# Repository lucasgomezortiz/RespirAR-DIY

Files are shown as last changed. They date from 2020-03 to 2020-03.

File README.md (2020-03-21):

# RespirAR DIY
###### Ante la urgencia y necesidad de los hospitales y centros de salud que combaten dia a dia con la Pandemia Covid-19(Coronavirus) buscamos la forma de generar un proyecto para aliviar la situacion actual, uno de los equipos mas necesiarios para combatir esta pandemia son los repiradores artifiales y de bajo presupuesto.
 
### EL PROYECTO ESTA EN FASE DESARROLLO
###### Toda ayuda es bienvenida para el desarrollo

Thingiverse: https://www.thingiverse.com/thing:4232749
fusion360: 

# Cualquier duda, sugerencia o aporte
Grupo de [facebook](https://www.facebook.com/groups/respiradormaker/) 
Instagram [@rejuntamaker](https://www.instagram.com/rejuntamaker/) [@lucasgomezortiz](https://www.instagram.com/lucasgomezortiz/)
### Este proyecto nace de [Reespirator](https://twitter.com/ReesistenciaT)

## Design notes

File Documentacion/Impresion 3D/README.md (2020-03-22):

# Adjunto los parametros utilizados en cada pieza

Para imprimir estas piezas no se requiere una gran impresora 3d, esta optimizado para cualquier tipo de impresoras fdm. 
*Ningun archivo requiere el uso de soportes, raft o balsa*

Aclaracion, las velocidades que utilice fueron a 75/mms por lo tanto el tiempo puede variar. pueden jugar con los datos que brindon, pero siempre pensado en la funcionalidad del dispositivo.
###### <u>MIS CONFIGURACION</u>
> **Flyingbear Ghost V4**
> Nozzle 0.5
> Tipo: Cerada
> Extrusor: Bowden
> S-Curve Acceleration
> Lineal Advance
> Version de Cura 4.4.1

> **Sura3D E1**
> Nozzle 0.4
> Tipo: abierta
> Extrusor: Bowden
> S-Curve Acceleration
> Lineal Advance
> Version de Cura 4.4.1

# ~~Acople OBSOLETO~~
> * Altura de capa: 0.2
> * Grosor de perimetro: 1mm
> * Cantidad de perimetros 3(Nozzle 0.5m) 4 * (Nozzle 0.4)
> * Infil: 25%
> * Patron: Lines
> * Ironing:Pattern ZigZag / Line Spacing 0.2
>> * Total: 00:07 Minutos

# AMBU
###### Piezas AMBU_A AMBU_B. Estas piezas lo ideal es imprimir con nozzle mas grandes (0.5 u 0.6)
> * Altura de capa: 0.35 (Nozzle 0.5)
> * Grosor de perimetro: 1mm
> * Cantidad de perimetros: 
> >* 3 (Nozzle 0.5m)
> >* 4 (Nozzle 0.4m)
> * Infil: 13%
> * Patron: Lines
> * Ironing:Pattern ZigZag / Line Spacing 0.2
>> * Total: 03:32hs C/U x2= 07:04hs

# Brazo/Puente
> * Altura de capa: 0.35 (Nozzle 0.5)
> * Grosor de perimetro: 1mm
> * Cantidad de perimetros: 
> >* 3 (Nozzle 0.5m)
> >* 4 (Nozzle 0.4m)
> * Infil: 10%
> * Patron: Lines
> * Ironing:Pattern ZigZag / Line Spacing 0.2
>> * Total: 01:20hs

###### Ender 3/PRO 
> * Rotar 45°
> * Ingresar cordenadas x 0.0119 Y 1.231

# Leva v0.3
> * Altura de capa: 0.35 (Nozzle 0.5)
> * Grosor de perimetro: 1mm
> * Cantidad de perimetros: 
> * Capas superiores e inferiores : 4 (1mm)
> >* 3 (Nozzle 0.5m)
> >* 4 (Nozzle 0.4m)
> * Infil: 13%
> * Patron: Lines
> * Ironing:Pattern ZigZag / Line Spacing 0.2
>> * Total: ~~02:07hs~~ 01:40hs

# Escuadras
> * Altura de capa: 0.35 (Nozzle 0.5)
> * Grosor de perimetro: 1mm
> * Cantidad de perimetros: 
> * Capas superiores e inferiores : 4 (1mm)
> >* 3 (Nozzle 0.5m)
> >* 4 (Nozzle 0.4m)
> * Infil: Se remplaza por perimetros
> * Patron: Lines
> * Ironing:Pattern ZigZag / Line Spacing 0.2
>> * Total: 00:57hs

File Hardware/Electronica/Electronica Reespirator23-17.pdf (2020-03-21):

### Sistema electrónico Reespirator

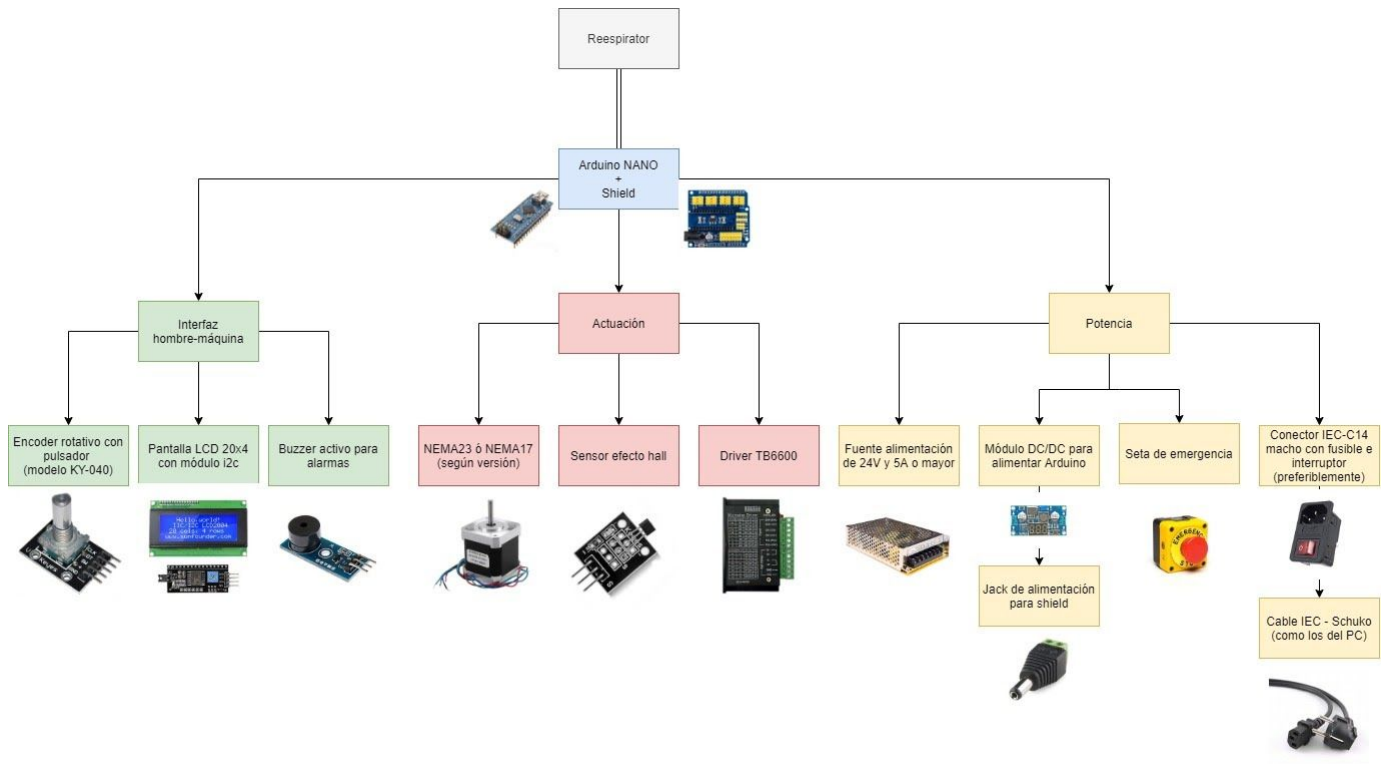
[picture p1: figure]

Se pretende hacer un sistema lo más sencillo posible, solo con los componentes que sean estrictamente necesarios y que estén disponibles en forma de módulo, para evitar soldaduras y montajes complicados.

Se ha separado el sistema en 4 grupos, que forman parte del Reespirator:
- Microcontrolador: se ha optado por un Arduino NANO con un shield para facilitar las conexiones
- Interfaz hombre-máquina
- Se utilizará un display de 20x4 con interfaz i2c para mostrar los datos y las configuraciones/menús.
- Para navegar por los menús y configurar parámetros se utilizará un encoder rotativo con pulsador (KY-040).
- Para avisar de alguna alarma se utilizará un zumbador activo.
- Sistema de actuación
- Se utilizarán motores NEMA, concretamente NEMA17 o NEMA23 según el modelo de Reespirator a fabricar.
- Los motores NEMA se controlarán con un driver TB6600. Se ha elegido este modelo ya que puede controlar tanto el NEMA23 como motores más pequeños sin necesidad de cambiar todo el hardware.
- Para monitorizar la posición inicial del sistema, se utilizará un sensor de efecto hall.
- Sistema de potencia / eléctrico
- Para alimentar todo el aparato se utilizará una fuente de alimentación a 24V con una salida igual o superior a 5A.
- Para alimentar el Arduino se utilizará un módulo DC/DC, preferiblemente uno regulable con display voltímetro.
- Si se utiliza el shield de Arduino NANO, se alimentará por el jack.

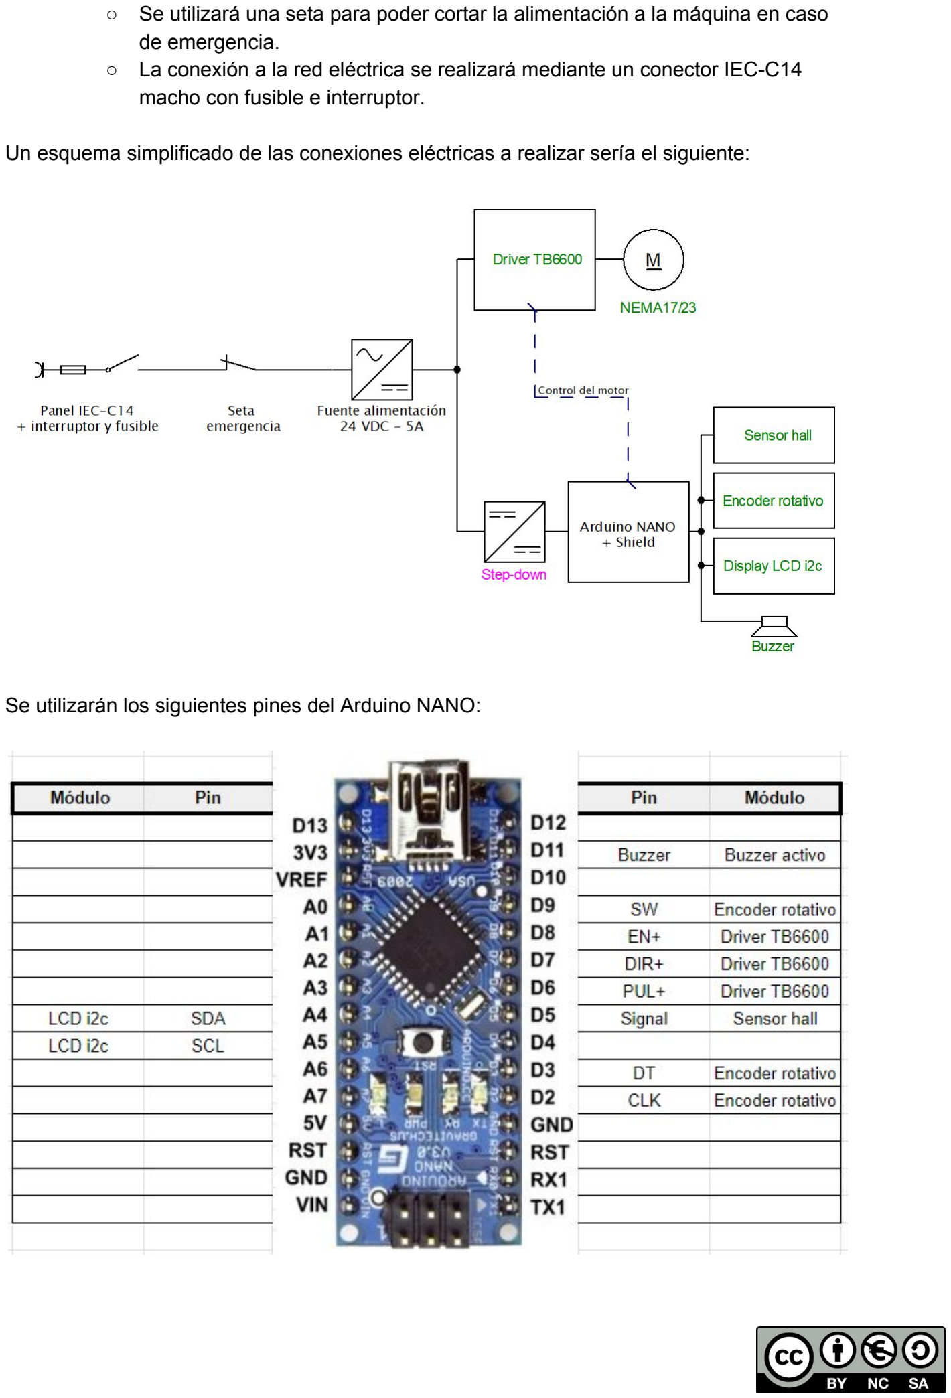
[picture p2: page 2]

- Se utilizará una seta para poder cortar la alimentación a la máquina en caso de emergencia.
- La conexión a la red eléctrica se realizará mediante un conector IEC-C14 macho con fusible e interruptor.

Un esquema simplificado de las conexiones eléctricas a realizar sería el siguiente:

Se utilizarán los siguientes pines del Arduino NANO:

Las conexiones se realizarán a través de los headers disponibles en los shields de Arduino NANO:

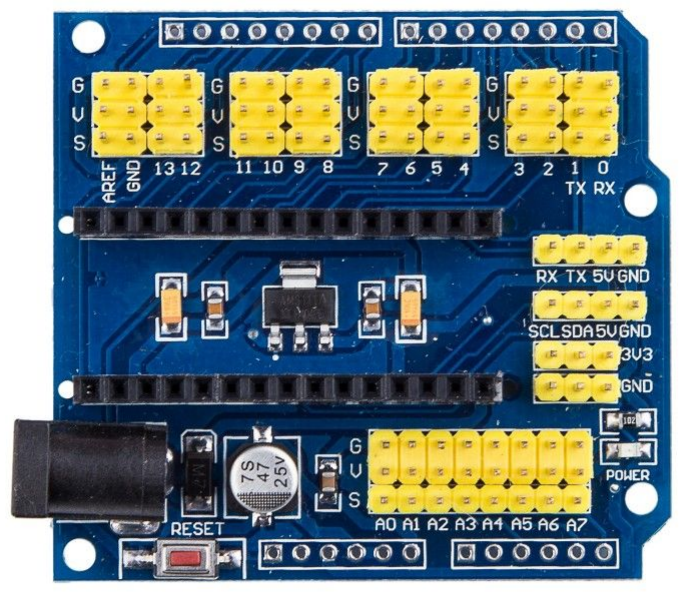
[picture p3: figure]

Descripción de las conexiones

- Pantalla LCD con módulo i2c

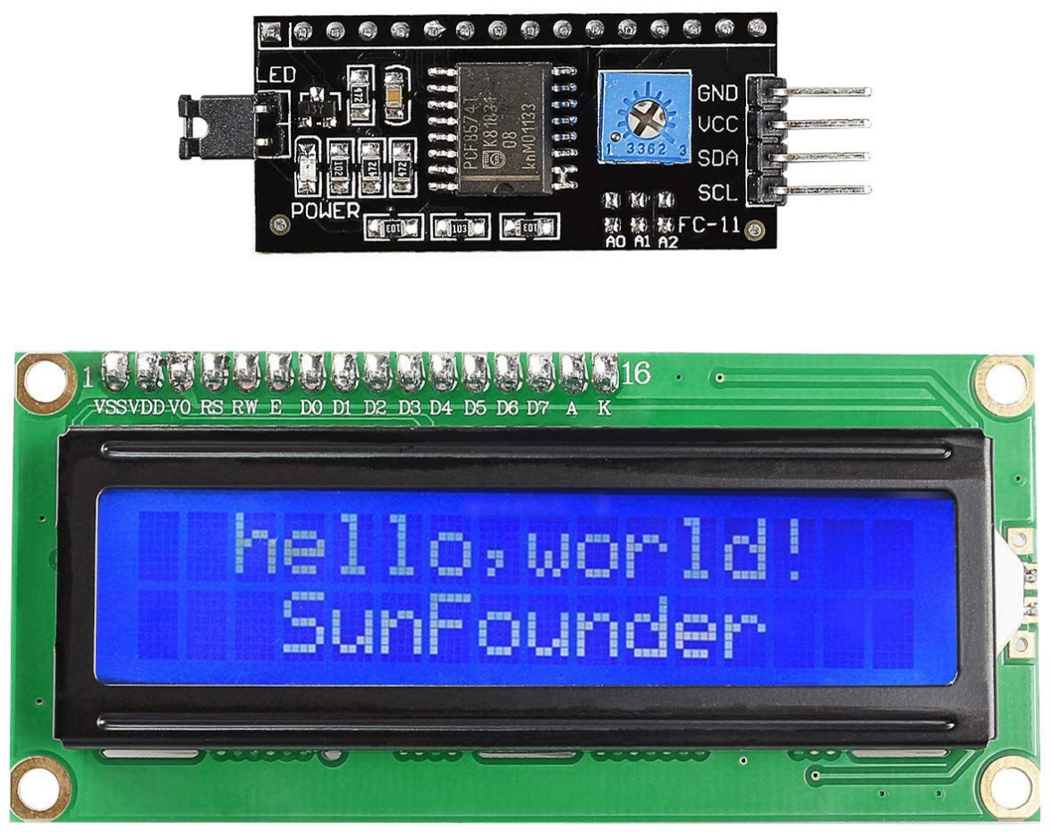
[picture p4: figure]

Son necesarios 4 cables tipo dupont hembra-hembra
- GND: conectado a la masa del Arduino
- VCC: conectado a la alimentación 5V del Arduino
- SDA: conectado al pin A4 del Arduino
- SCL: conectado al pin A5 del Arduino

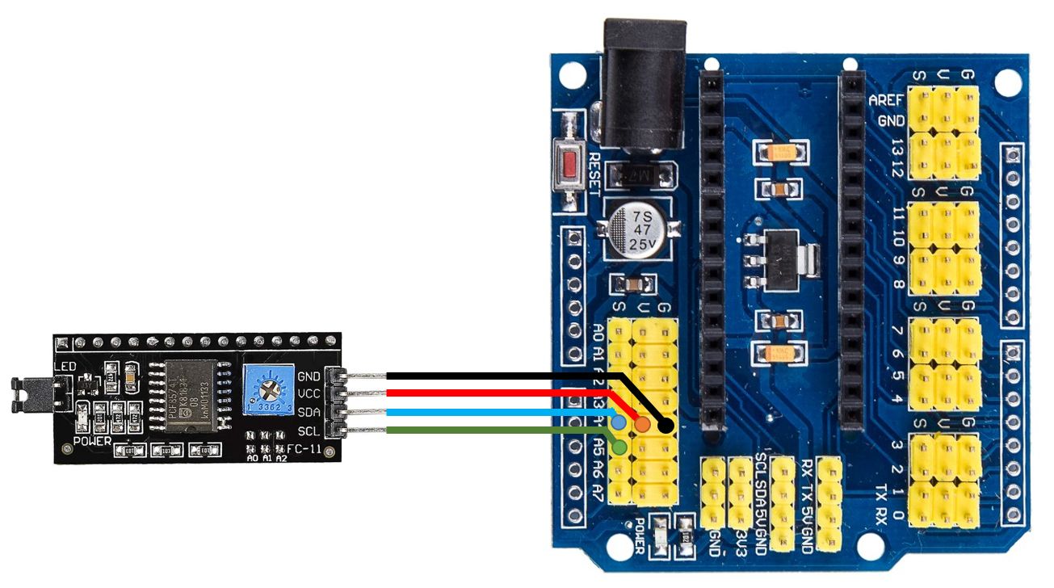
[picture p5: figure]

- Encoder rotativo con pulsador KY-040

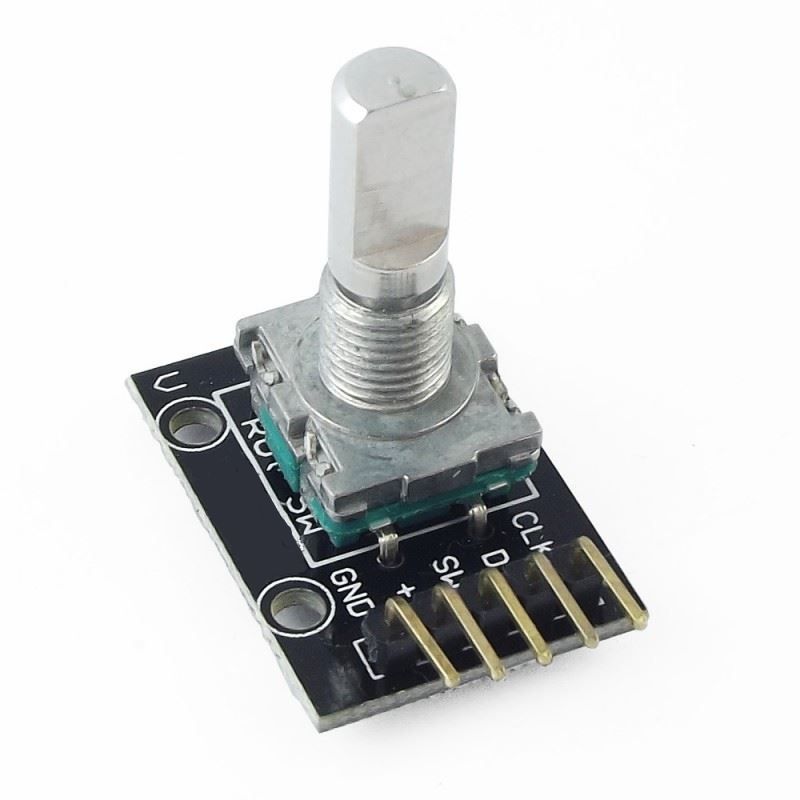
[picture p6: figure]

Son necesarios 5 cables tipo dupont hembra-hembra
- CLK: conectado al pin D2 del Arduino
- DT: conectado al pin D3 del Arduino
- SW: conectado al pin D9 del Arduino
- +: conectado a la alimentación 5V del Arduino
- GND: conectado a la masa del Arduino

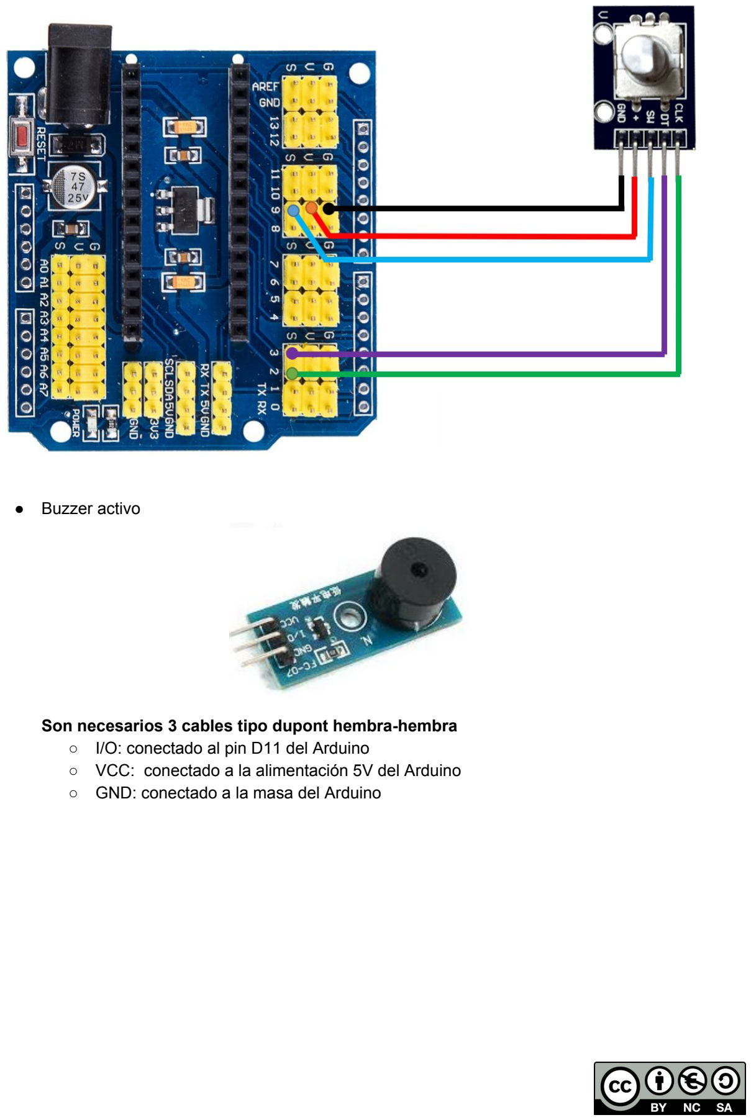
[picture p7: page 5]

- Buzzer activo

Son necesarios 3 cables tipo dupont hembra-hembra
- I/O: conectado al pin D11 del Arduino
- VCC: conectado a la alimentación 5V del Arduino
- GND: conectado a la masa del Arduino

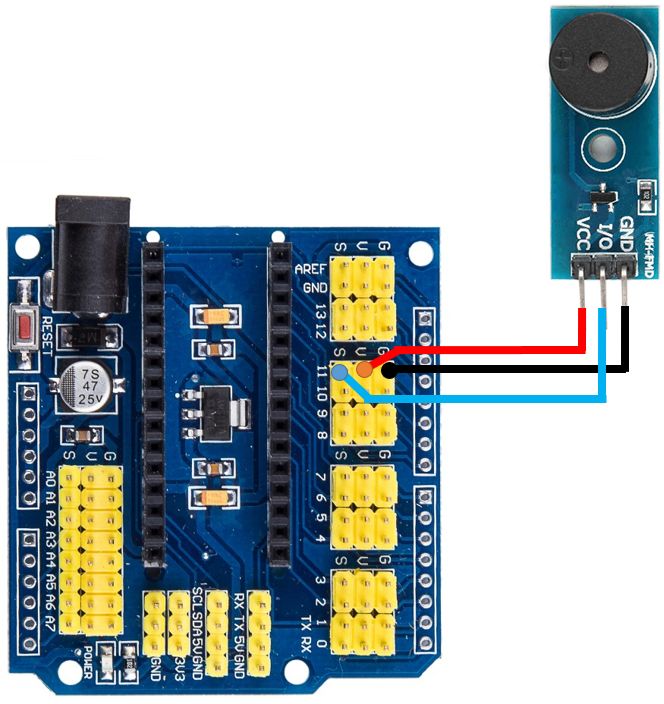
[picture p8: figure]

- Sensor efecto hall

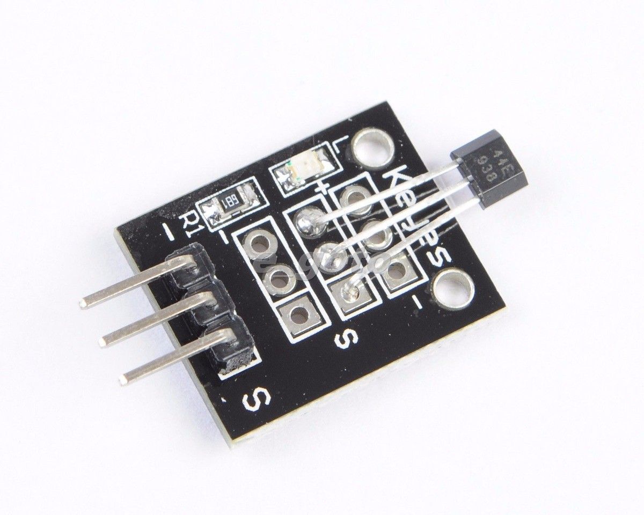
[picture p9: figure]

Son necesarios 3 cables tipo dupont hembra-hembra
- - (GND): conectado a la masa del Arduino
- + (VCC): conectado a la alimentación 5V del Arduino
- S (Signal): conectado al pin D5 del Arduino

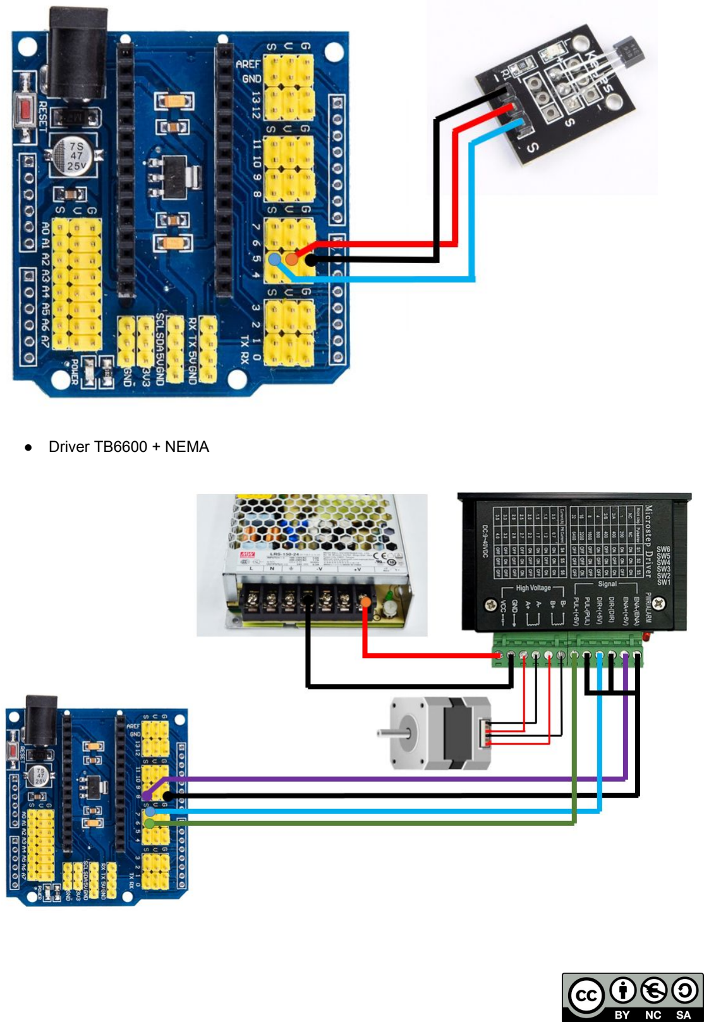
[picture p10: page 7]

- Driver TB6600 + NEMA

Señales de control: se deben cablear desde el shield/Arduino con un cable dupont hembra-macho o con un cable dupont hembra con un extremo pelado.
- ENA(+): conectado al pin D8 del Arduino
- DIR(+): conectado al pin D7 del Arduino
- PUL(+): conectado al pin D6 del Arduino (PWM)
- ENA(-): conectado a la masa del Arduino
- DIR(-): conectado a la masa del Arduino
- PUL(-): conectado a la masa del Arduino
Señales del motor: se conectarán directamente los cables pelados del motor paso a paso. Los colores del cableado pueden cambiar según el motor utilizado, consultar el datasheet del motor antes de poner la máquina en marcha.
- B- y B+: conectado a la fase B del motor paso a paso
- A- y A+: conectado a la fase A del motor paso a paso
Señales de potencia: se conectarán directamente desde la fuente de alimentación (V+ y V-) con cable rojo y negro (o del que se disponga) de sección AWG 20 / 0.5mm2 o superior (recomendado).
- VCC: conectado al positivo de la fuente de 24V
- GND: conectado a la masa de la fuente de 24V
Posición de los switches del driver (comprobar en la serigrafía del driver):
- SW1, SW2 y SW3: ON (sin microsteps)
- SW4, SW5 y SW6: OFF (máxima corriente)
- Regulador step-down

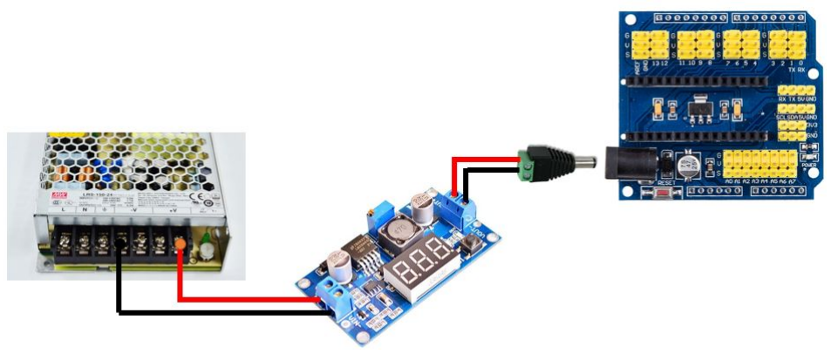
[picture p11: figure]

Señales de potencia: se conectarán directamente desde la fuente de alimentación (V+ y V-) con cable rojo y negro (o del que se disponga) de sección AWG 20 / 0.5mm2 o superior (recomendado).
- VIN+: conectado al positivo de la fuente de 24V
- GND: conectado a la masa de la fuente de 24V
- Se debe ajustar el nivel de tensión girando el potenciómetro de ajuste con un destornillador antes de terminar el montaje, sin conectar la salida, con la ayuda del display voltímetro. Si se utiliza junto con el shield de el Arduino

NANO recomendamos su uso a 9 VDC. Si no tiene display, habrá que medir con un multímetro el voltaje de salida.

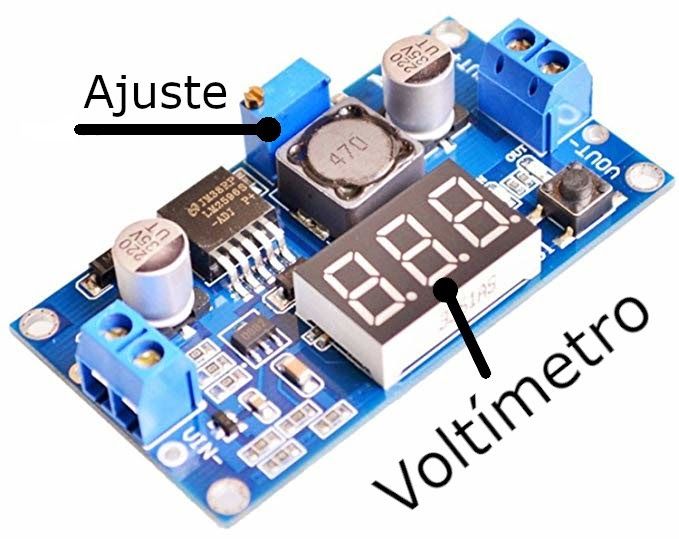
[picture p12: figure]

Señales de salida: se conectarán desde la salida del módulo hasta el conector jack que alimenta el shield con cable rojo y negro de sección AWG 20 / 0.5 mm2 o superior (recomendado).
- VOUT+: conectado al pin Vin del Arduino o al jack del Shield
- GND: conectado a la masa del Arduino o al jack del Shield
- Conectar el jack al jack hembra del shield de Arduino.

CONEXIONADO DE CORRIENTE ALTERNA

Para las conexiones de alterna barajamos tres situaciones.

Situación A con posibilidad de crimpar cable

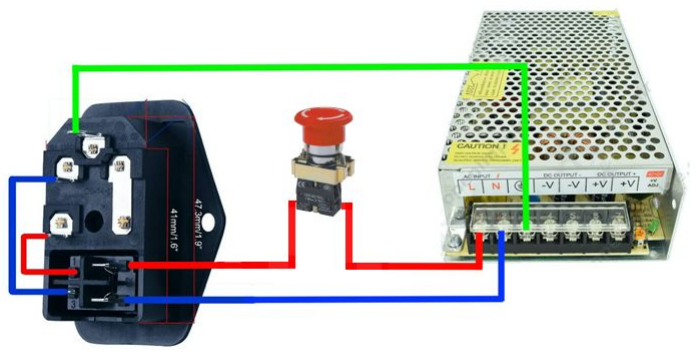
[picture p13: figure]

- Conector IEC-C14
La toma de tierra irá con cable crimpado directo a la toma de tierra de la fuente de alimentación.
Los otros dos terminales irán conectados a los terminales de entrada del interruptor, también con cable crimpado.
Una de las salidas del interruptor irá conectada a la entrada del pulsador de emergencia. También se conectará la salida del pulsador de emergencia a la entrada L de la fuente de alimentación.
La salida del interruptor restante irá conectada directamente a la entrada N de la fuente de alimentación.

Situación B con posibilidad de soldar cable:
En el caso de no contar con material para crimpar los terminales, se podrá optar por soldar la conexiones del conector e interruptor; ya que el pulsador de emergencia y la fuente de alimentación llevarán los cables atornillados.

Situación C sin posibilidad de soldar/ crimpar cable.

Si no se dispone de herramientas para soldar ni crimpar se cableará directamente a la fuente pasando solo la fase por la seta de emergencia:

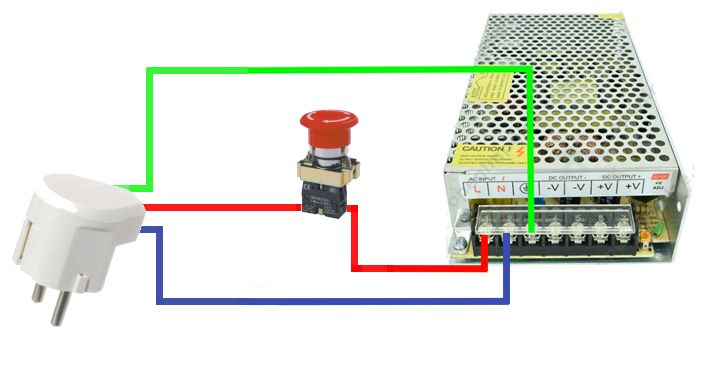
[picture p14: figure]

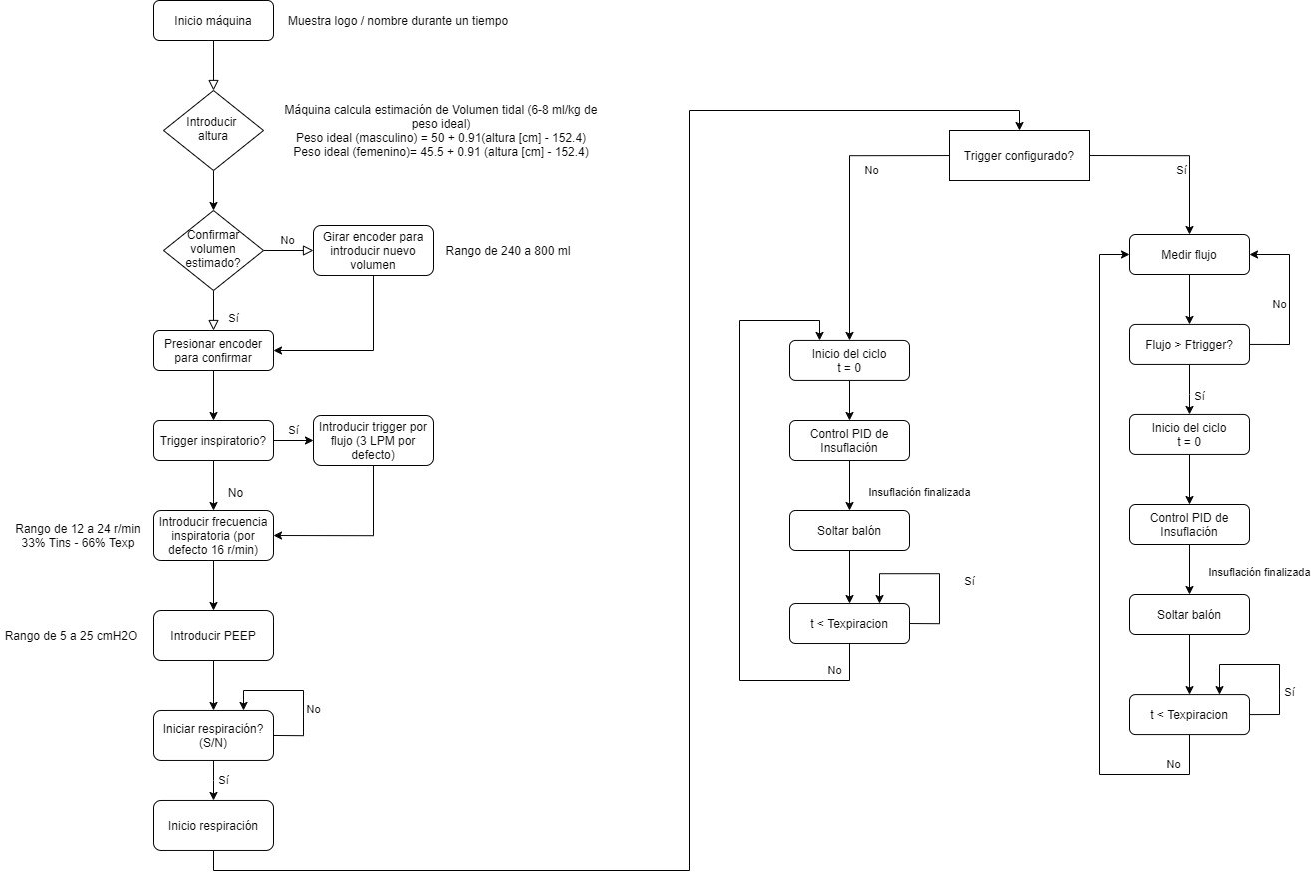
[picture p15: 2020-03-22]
Documentacion/Diagrama.png

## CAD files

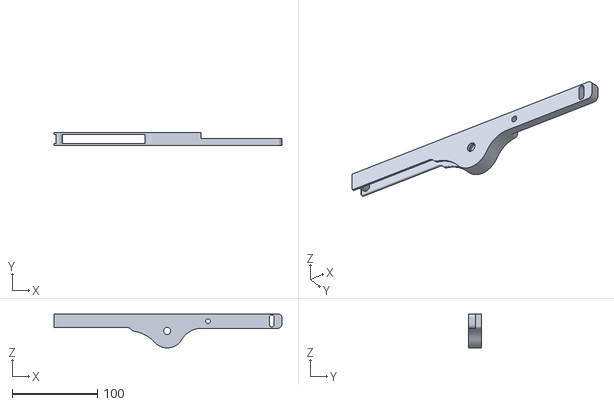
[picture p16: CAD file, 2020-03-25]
Hardware/Respirador/STL/Producion/Brazo final.stl
268.1 x 15.0 x 39.8

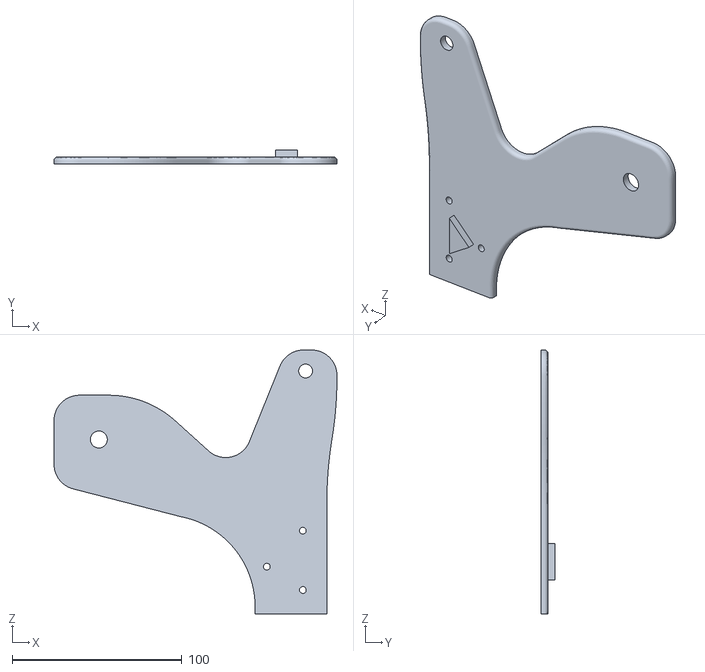
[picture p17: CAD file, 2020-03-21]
Hardware/Respirador/STL/Pruebas/Placa_b.stl
166.8 x 8.00 x 155.6

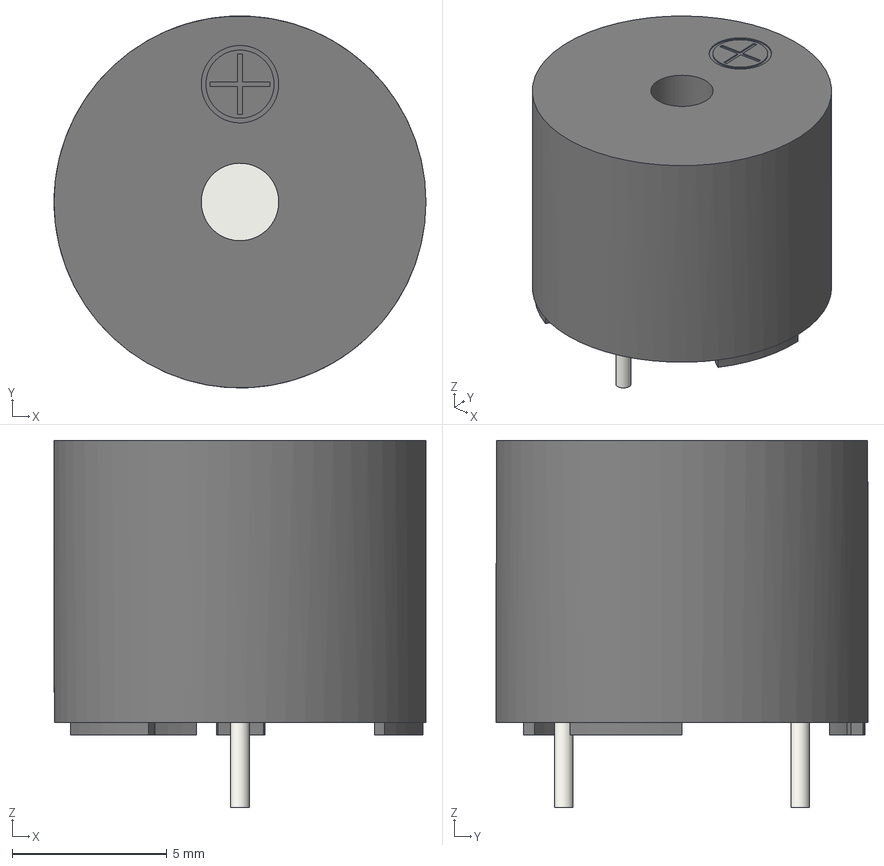
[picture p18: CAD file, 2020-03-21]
Hardware/Electronica/PCB/REES Kicad/Modelos 3D/TMB12A05.step
12.0 x 12.0 x 11.9 mm

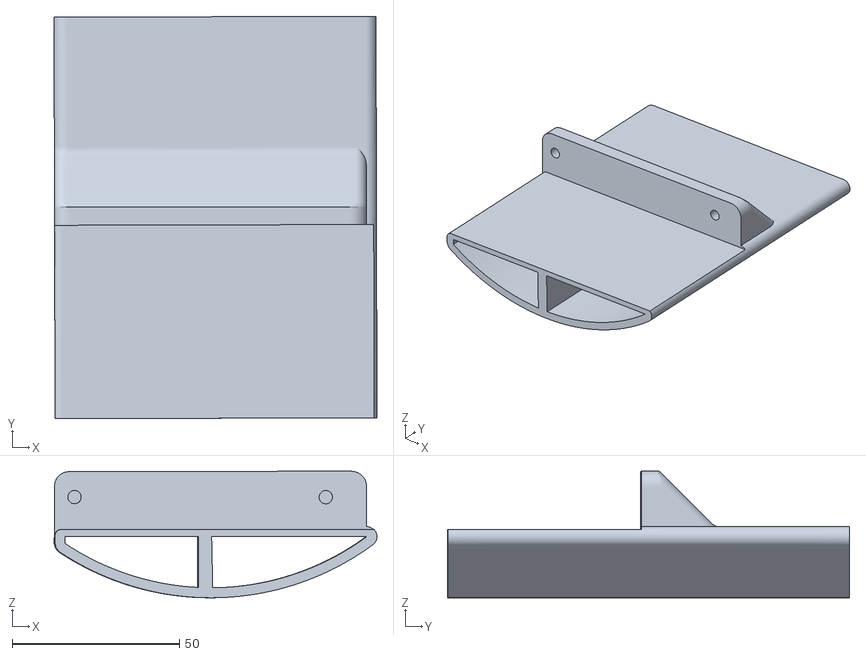
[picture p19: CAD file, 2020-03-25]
Hardware/Respirador/STL/Producion/Presionador.stl
96.5 x 120.2 x 37.9

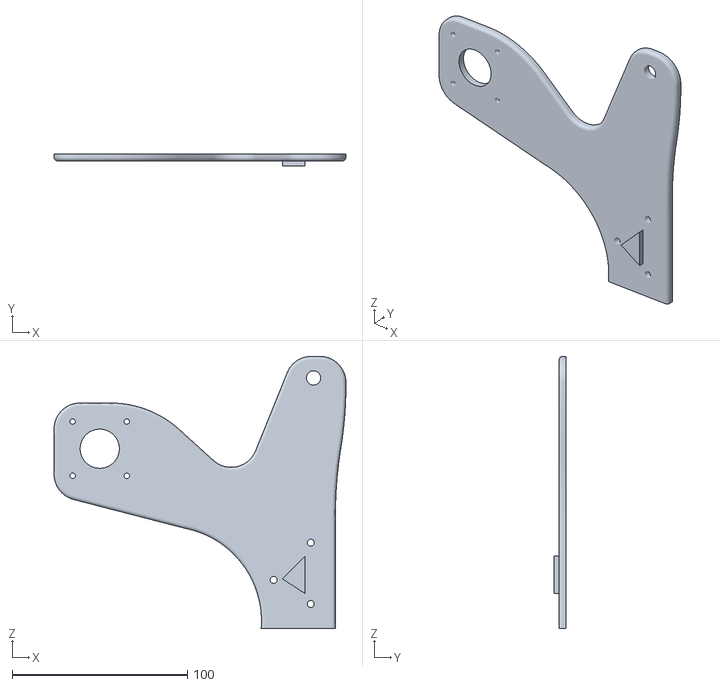
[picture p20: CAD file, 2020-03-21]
Hardware/Respirador/STL/Pruebas/Placa_a.stl
166.8 x 7.00 x 155.6

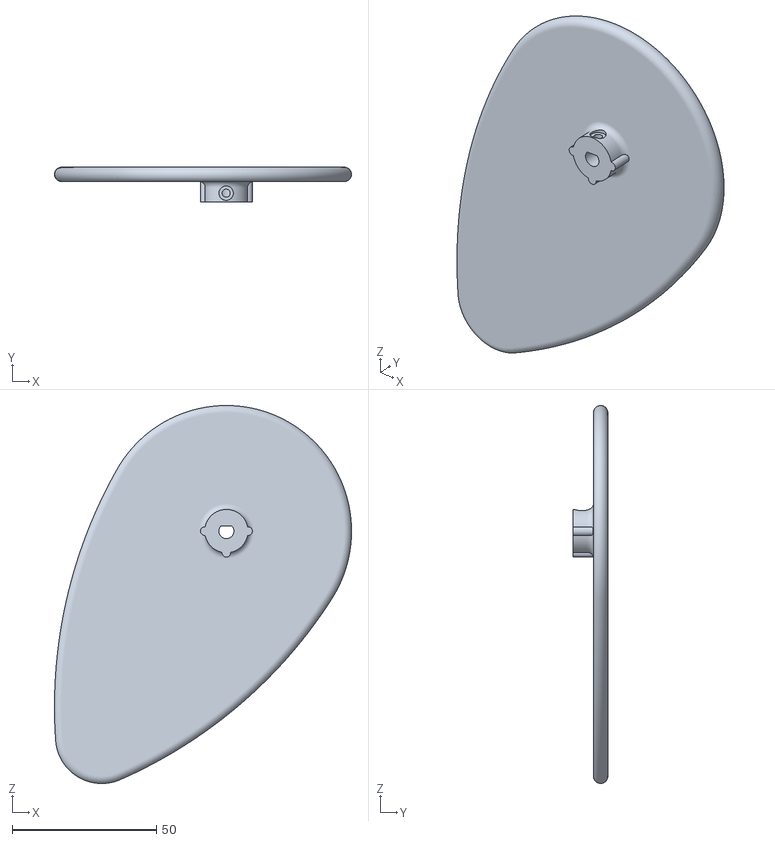
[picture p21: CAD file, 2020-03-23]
Hardware/Respirador/STL/Producion/Leva final.stl
102.9 x 12.0 x 130.9

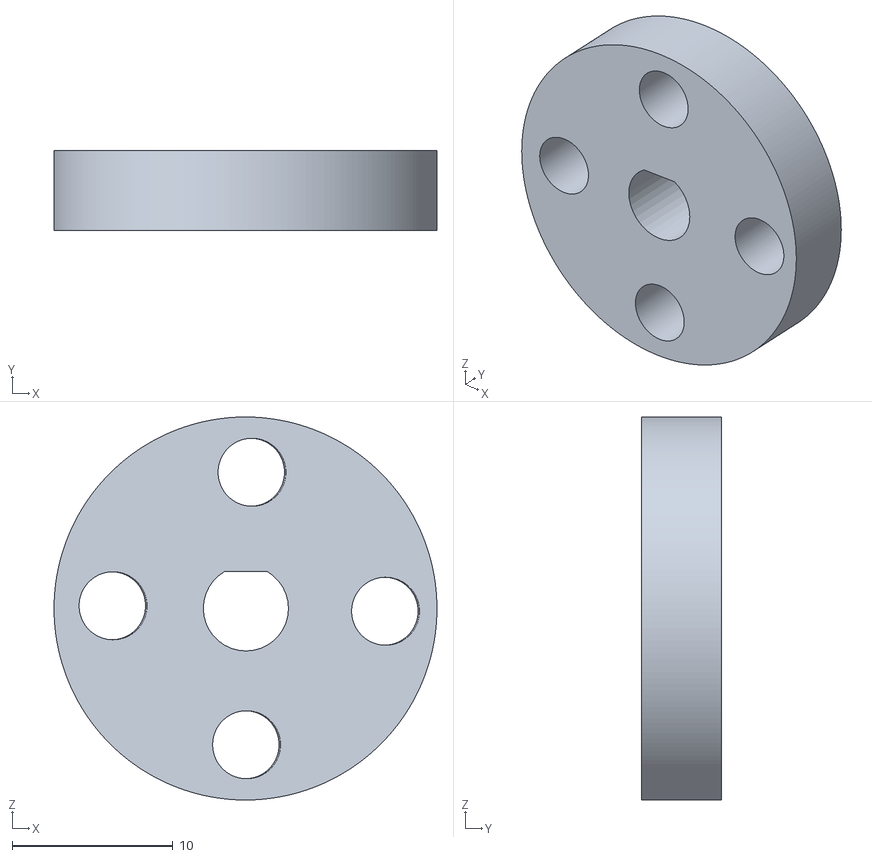
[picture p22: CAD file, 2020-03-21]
Hardware/Respirador/STL/Pruebas/acople.stl
23.8 x 5.00 x 23.8

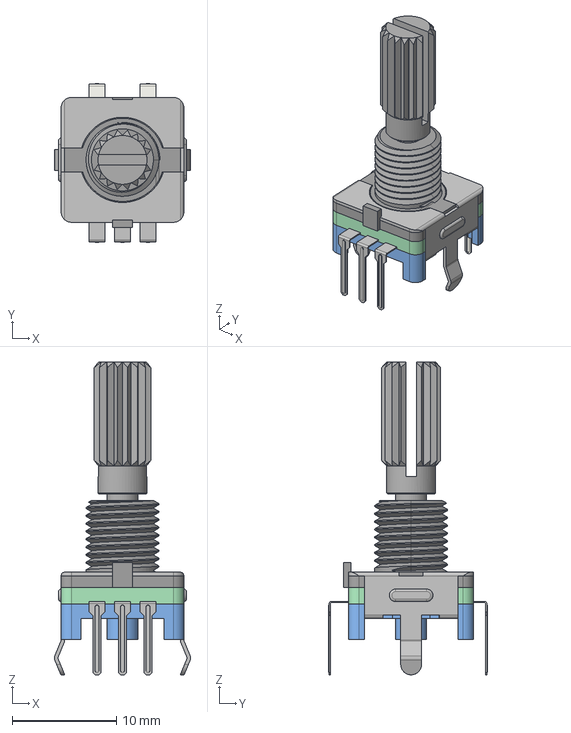
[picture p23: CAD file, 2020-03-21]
Hardware/Electronica/PCB/REES Kicad/Modelos 3D/EC11_Rotary_Encoder_Switched.step
13.1 x 15.3 x 30.1 mm

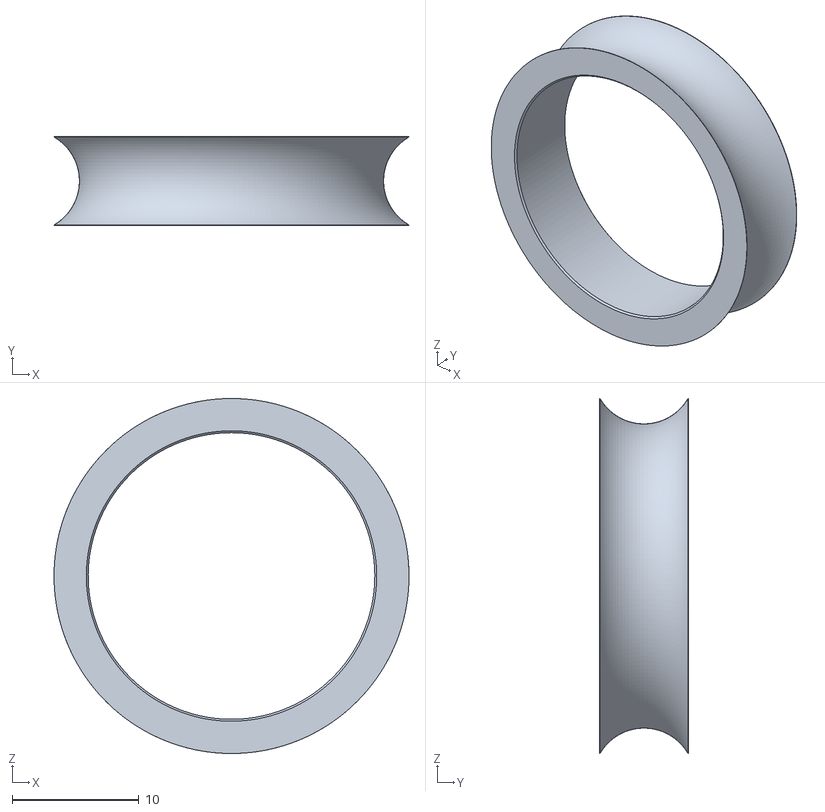
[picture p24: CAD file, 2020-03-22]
Hardware/Respirador/STL/Producion/guia leva.stl
28.0 x 7.00 x 28.0

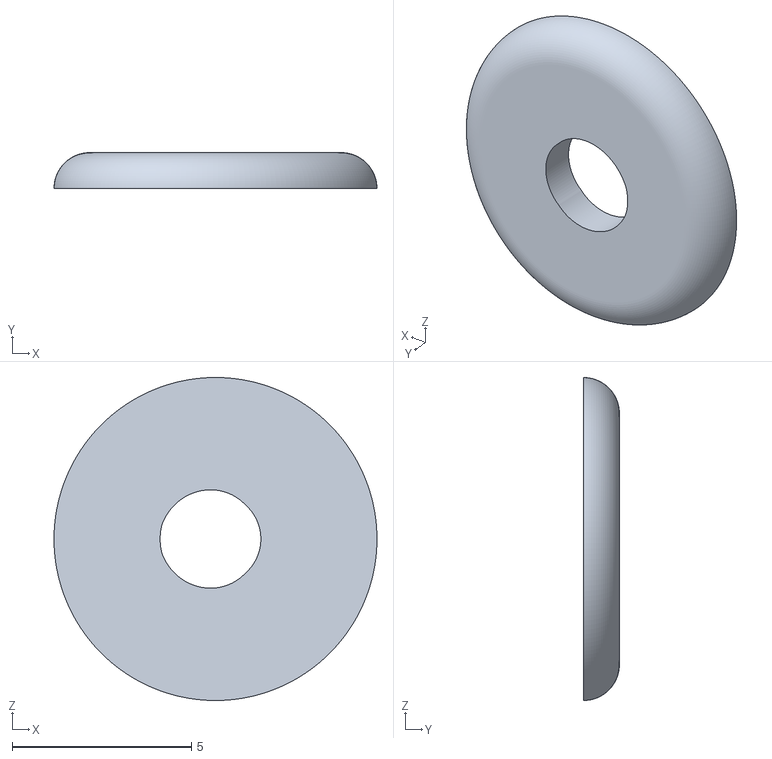
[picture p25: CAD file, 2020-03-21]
Hardware/Respirador/STL/Pruebas/arandela brazox3.stl
9.00 x 1.00 x 9.00

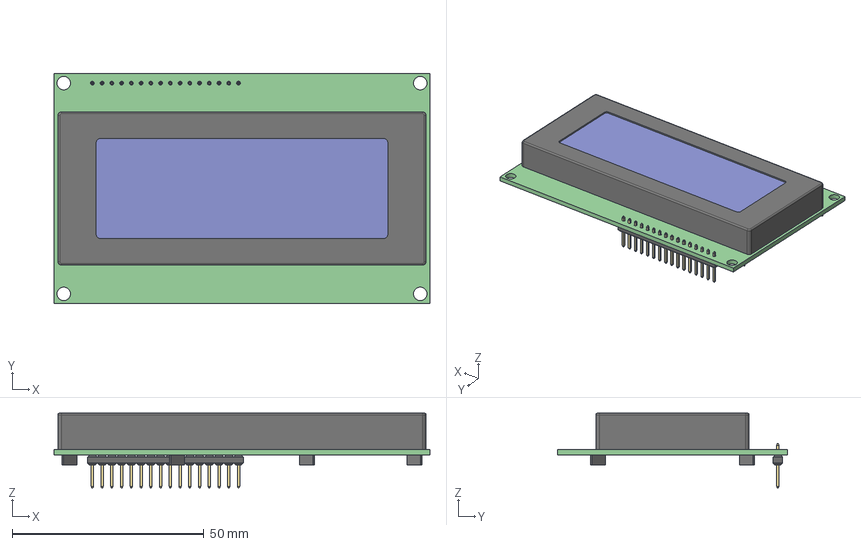
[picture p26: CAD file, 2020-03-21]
Hardware/Electronica/PCB/REES Kicad/Modelos 3D/QP5522 Jaycar 20x4 LCD Module v14.step
98.0 x 60.0 x 19.5 mm

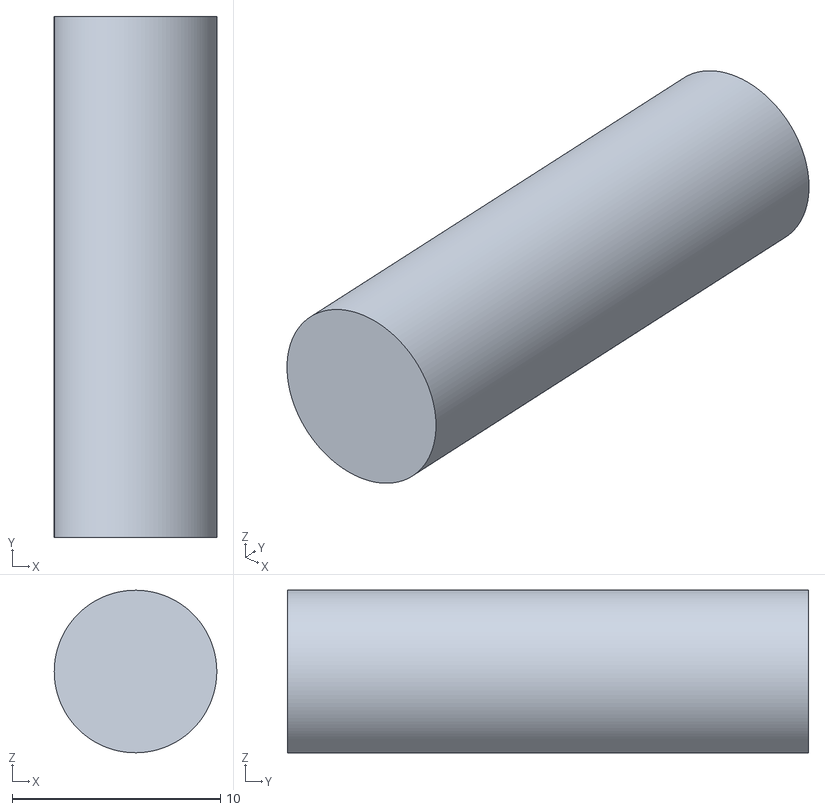
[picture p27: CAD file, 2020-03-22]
Hardware/Respirador/STL/Producion/Brazo traba.stl
7.80 x 25.0 x 7.80

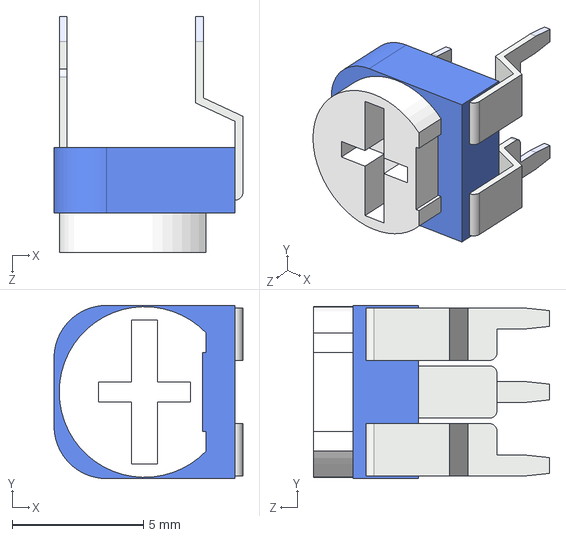
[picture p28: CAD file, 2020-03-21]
Hardware/Electronica/PCB/REES Kicad/Modelos 3D/Potentiometer Blue.STEP
7.20 x 6.60 x 9.00 mm

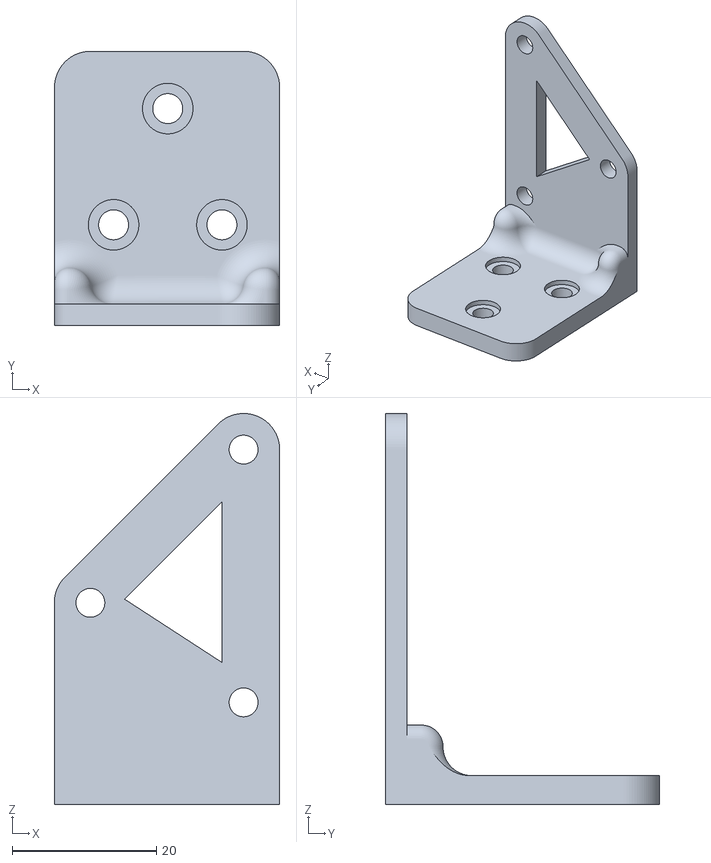
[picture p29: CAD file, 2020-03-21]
Hardware/Respirador/STL/Producion/Escuadra_a.stl
31.2 x 38.0 x 54.1

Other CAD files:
Hardware/Electronica/PCB/REES Kicad/Modelos 3D/LM7805.STEP
Hardware/Respirador/STL/Producion/Escuadra_B.stl
Hardware/Respirador/STL/Producion/Ambu_b.stl
Hardware/Respirador/STL/Producion/Ambu_a.stl
Hardware/Electronica/PCB/REES Kicad/Modelos 3D/022057038.stp
Hardware/Electronica/PCB/REES Kicad/Modelos 3D/022057048.stp
Hardware/Electronica/PCB/REES Kicad/Modelos 3D/22057028.stp

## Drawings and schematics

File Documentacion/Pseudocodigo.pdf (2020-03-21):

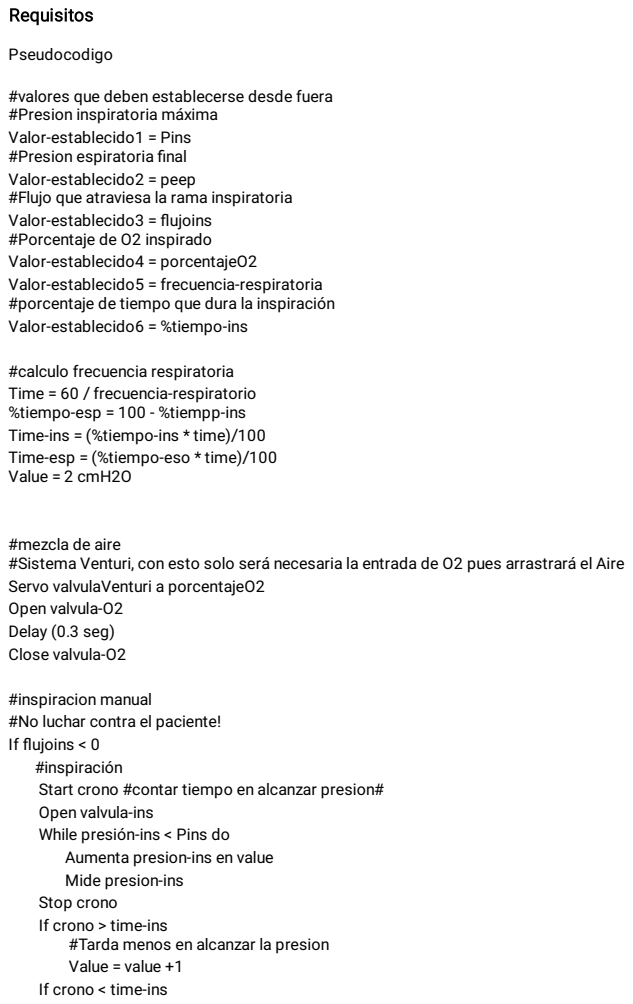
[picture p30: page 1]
Requisitos; Pseudocodigo

#valores que deben establecerse desde fuera
#Presion inspiratoria máxima
Valor-establecido1 = Pins
#Presion espiratoria final
Valor-establecido2 = peep
#Flujo que atraviesa la rama inspiratoria
Valor-establecido3 = flujoins
#Porcentaje de O2 inspirado
Valor-establecido4 = porcentajeO2
Valor-establecido5 = frecuencia-respiratoria
#porcentaje de tiempo que dura la inspiración
Valor-establecido6 = %tiempo-ins

#calculo frecuencia respiratoria
Time = 60 / frecuencia-respiratorio
%tiempo-esp = 100 - %tiempp-ins
Time-ins = (%tiempo-ins * time)/100
Time-esp = (%tiempo-eso * time)/100
Value = 2 cmH2O

#mezcla de aire
#Sistema Venturi, con esto solo será necesaria la entrada de O2 pues arrastrará el Aire
Servo valvulaVenturi a porcentajeO2
Open valvula-O2
Delay (0.3 seg)
Close valvula-O2

#inspiracion manual
#No luchar contra el paciente!
If flujoins < 0
#inspiración
Start crono #contar tiempo en alcanzar presion#
Open valvula-ins
While presión-ins < Pins do
Aumenta presion-ins en value
Mide presion-ins
Stop crono
If crono > time-ins
#Tarda menos en alcanzar la presion
Value = value +1
If crono < time-ins

Time-delay = time-ins - crono
Delay (time-delay)
If crono < (time-ins * 3)/4
#Tarda más, reduce la presión media en el pulmón Value = value - 1

Close valvula-ins

#Inspiracion

Start crono #contar tiempo en alcanzar presion# Open valvula-ins
While presión-ins < Pins do
Aumenta presion-ins en value
Mide presion-ins
Stop crono
If crono > time-ins
Value = value +1
If crono < time-ins
Time-delay-ins = time-ins - crono Delay (time-delay-ins)
If crono < (time-ins * 3)/4
Value = value - 1
Close valvula-ins

#Espiracion

Open valvula-esp
Start crono
While valvula-esp is open do Mide presion-esp
If presion-esp < peep
Stop crono
Close valvula-esp
Time-delay-esp= time-esp - crono Delay (time-delay-esp)

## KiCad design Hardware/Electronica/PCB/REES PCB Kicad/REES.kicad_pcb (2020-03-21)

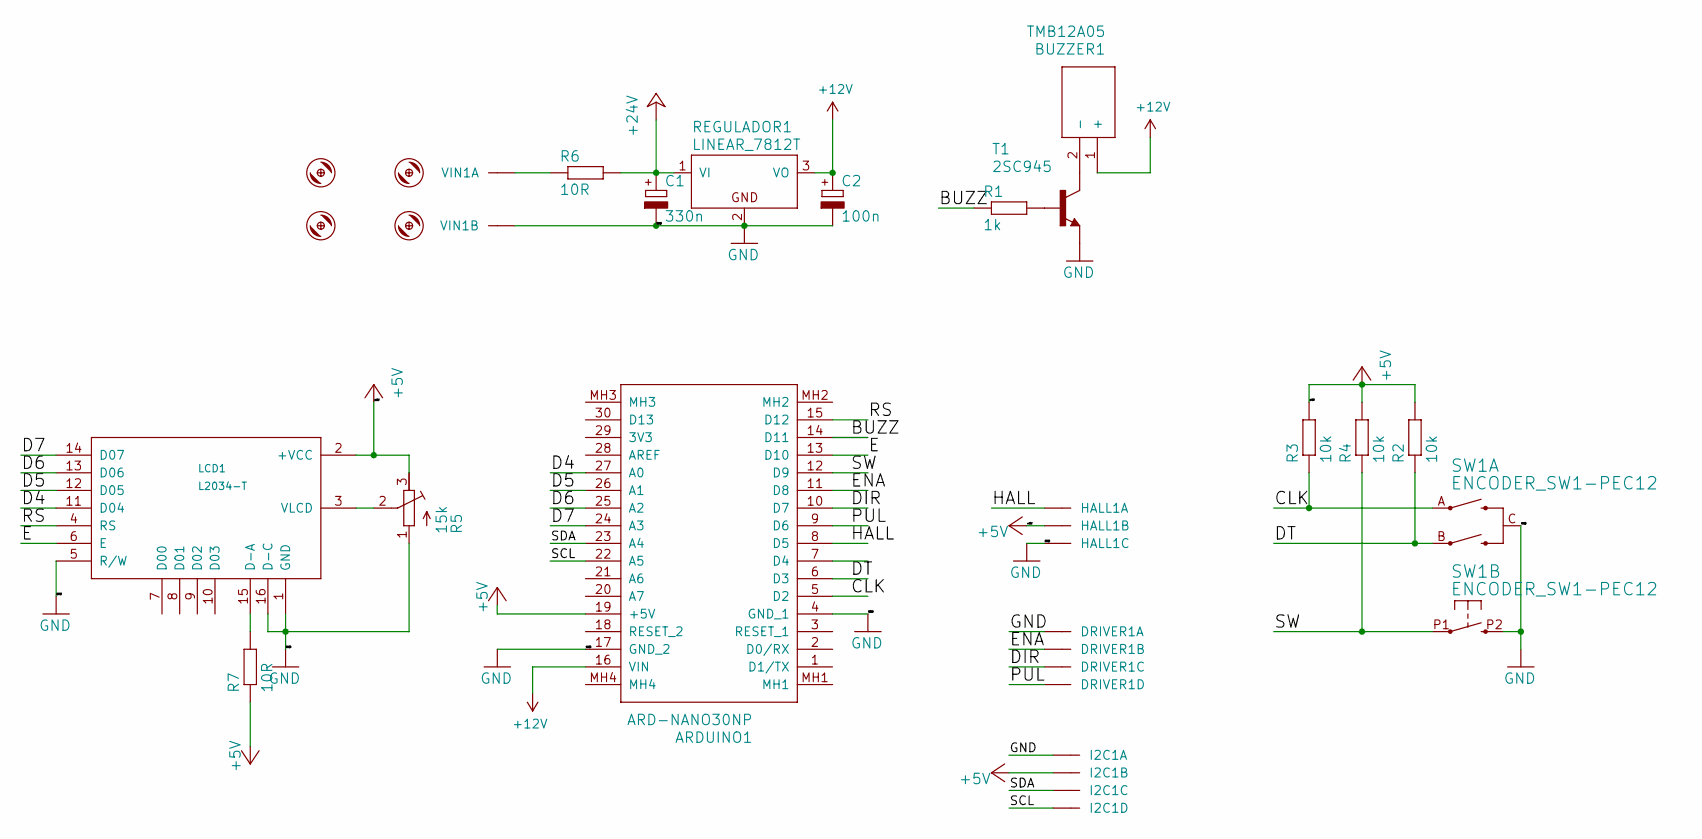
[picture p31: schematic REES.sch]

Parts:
ARDUINO1: ARD-NANO30NP; ARDNANO30NP
BUZZER1: TMB12A05
C1: 330n; E1,8-4
C2: 100n; E1,8-4
DRIVER1: 22-?-0405-7048; 7395-04
H1, H2, H3, H4: HOLES_MOUNT-HOLE3.6; HOLES_3,6
HALL1: 22-?-0305-7038; 7395-03
I2C1: 22-?-0405-7048; 7395-04
LCD1: L2034-T
R1: 1k; 0204_7
R2, R3, R4: 10k; 0204_7
R5: 15k; RTRIM3339P
R6: 10R; R_Axial_DIN0414_L11.9mm_D4.5mm_P15.24mm_Horizontal
R7: 10R; 0204_7
REGULADOR1: LINEAR_7812T; LINEAR_TO220H
SW1: ENCODER_SW1-PEC12; PEC12_INCREMENTAL_ENCODER
T1: 2SC945; TO92-ECB
VIN1: 22-?-0205-7028; 7395-02

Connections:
+5V: ARDUINO1.19 (+5V), HALL1.2, I2C1.2, LCD1.2 (+VCC), R2.2, R3.2, R4.2, R5.3 (E), R7.1
+12V: ARDUINO1.16 (VIN), BUZZER1.1 (+), C2.+, REGULADOR1.3 (VO)
+24V: C1.+, R6.2, REGULADOR1.1 (VI)
/BUZZ: ARDUINO1.14 (D11), R1.1
/CLK: ARDUINO1.5 (D2), R3.1, SW1.A
/D4: ARDUINO1.27 (A0), LCD1.11 (D04)
/D5: ARDUINO1.26 (A1), LCD1.12 (D05)
/D6: ARDUINO1.25 (A2), LCD1.13 (D06)
/D7: ARDUINO1.24 (A3), LCD1.14 (D07)
/DIR: ARDUINO1.10 (D7), DRIVER1.3
/DT: ARDUINO1.6 (D3), R2.1, SW1.B
/E: ARDUINO1.13 (D10), LCD1.6 (E)
/ENA: ARDUINO1.11 (D8), DRIVER1.2
/HALL: ARDUINO1.8 (D5), HALL1.1
/PUL: ARDUINO1.9 (D6), DRIVER1.4
/RS: ARDUINO1.15 (D12), LCD1.4 (RS)
/SCL: ARDUINO1.22 (A5), I2C1.4
/SDA: ARDUINO1.23 (A4), I2C1.3
/SW: ARDUINO1.12 (D9), R4.1, SW1.P1 (1)
GND: ARDUINO1.4 (GND_1), ARDUINO1.17 (GND_2), C1.-, C2.-, DRIVER1.1, HALL1.3, I2C1.1, LCD1.1 (GND), LCD1.5 (R/W), LCD1.16 (D-C), R5.1 (A), REGULADOR1.2 (GND), SW1.C, SW1.P2 (2), T1.E, VIN1.2
unnamed: BUZZER1.2 (-), T1.C
unnamed: LCD1.3 (VLCD), R5.2 (S)
unnamed: LCD1.15 (D-A), R7.2
unnamed: R1.2, T1.B
unnamed: R6.1, VIN1.1

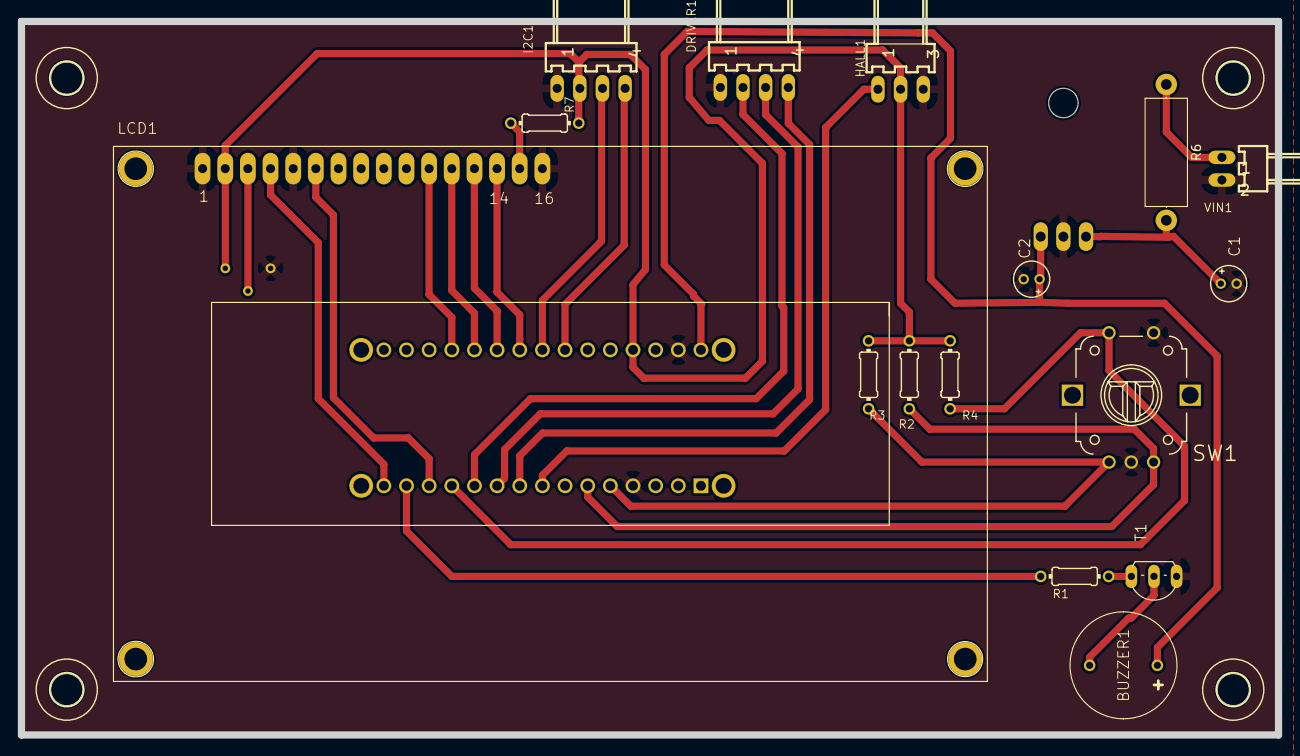
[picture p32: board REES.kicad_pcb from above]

Board: 2 copper layers, 141.0 x 80.0 mm, 23 parts (0 on the bottom side), 25 nets.

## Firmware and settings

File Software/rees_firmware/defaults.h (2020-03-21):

#ifndef DEFAULTS_H
#define DEFAULTS_H

#undef I2C // definido = Display i2c, sin definir Display parallel

// Valores motor
#define DEFAULT_PASOS_POR_REVOLUCION 200 // Suponiendo un motor de 200 pasos/rev sin microstepper
#define DEFAULT_ACELERACION 6000
#define DEFAULT_MICROSTEPPER 16

// Valores por defecto
#define DEFAULT_ESTATURA 170 // cm
#define DEFAULT_SEXO 0 // 0: varón, 1: mujer
#define DEFAULT_ML_POR_KG_DE_PESO_IDEAL 7
#define DEFAULT_MAX_VOLUMEN_TIDAL 800
#define DEFAULT_MIN_VOLUMEN_TIDAL 240
#define DEFAULT_FLUJO_TRIGGER 3
#define DEFAULT_RPM 15
#define DEFAULT_MAX_RPM 24
#define DEFAULT_MIN_RPM 14
#define DEFAULT_POR_INSPIRATORIO 60


#endif // DEFAULTS_H

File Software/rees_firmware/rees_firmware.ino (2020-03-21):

// =========================================================================
// DEPENDENCIAS
// =========================================================================

#include "defaults.h"
#include "utils.h"
#include "pinout.h"
#include "Display.h"
#include "Encoder.h"
#include "MechVentilation.h"
#include "src/AccelStepper/AccelStepper.h"

// =========================================================================
// VARIABLES
// =========================================================================

int rpm                    = DEFAULT_RPM;
int porcentajeInspiratorio = DEFAULT_POR_INSPIRATORIO;
int estatura               = DEFAULT_ESTATURA;
int sexo                   = DEFAULT_SEXO;
int microStepper           = DEFAULT_MICROSTEPPER;
int aceleracion            = DEFAULT_ACELERACION * microStepper;
int pasosPorRevolucion     = DEFAULT_PASOS_POR_REVOLUCION;
float flujoTrigger         = DEFAULT_FLUJO_TRIGGER;

bool tieneTrigger;
bool modo = true, errorFC = false;
int volumenTidal;
float speedIns, speedEsp, tCiclo, tIns, tEsp;

// pines en pinout.h
AccelStepper stepper(
  AccelStepper::DRIVER,
  DIRpin,
  PULpin
); // direction Digital 6 (CW), pulses Digital 7 (CLK)
Encoder encoder(
  DTpin,
  CLKpin,
  SWpin
);
Display display = Display();
MechVentilation ventilation;

// =========================================================================
// SETUP
// =========================================================================

void setup()
{

  // INICIALIZACION
  // =========================================================================

  // Puerto serie
  Serial.begin(9600);
  Serial.println("Inicio");

  // Display de inicio
  display.writeLine(0, "REESPIRATOR");

  // Zumbador
  pinMode(BUZZpin, OUTPUT);
  digitalWrite(BUZZpin, HIGH); // test zumbador
  delay(100);
  digitalWrite(BUZZpin, LOW);

  // FC efecto hall
  pinMode(ENDSTOPpin, INPUT); // el sensor de efecto hall da un 1 cuando detecta

  // Parte motor
  pinMode(ENpin, OUTPUT);
  digitalWrite(ENpin, LOW);

  Serial.println("Setup");
  stepper.setAcceleration(aceleracion);

  // deja la display en blanco
  delay(1000);
  display.clear();
  delay(100);


  // INTERACCIÓN: ESTATURA
  // =========================================================================
  display.writeLine(0, "Introduce estatura");
  while(!encoder.readButton()) {
    encoder.updateValue(&estatura);
    display.writeLine(1, "Altura: " + String(estatura) + " cm");
  }
  display.writeLine(0, "Valor guardado");
  display.writeLine(1, "Altura: " + String(estatura) + " cm");
  Serial.println("Altura (cm): " + String(estatura));
  delay(1000);
  display.clear();


  // INTERACCIÓN: SEXO
  // =========================================================================
  display.writeLine(0, "Introduce sexo");
  while(!encoder.readButton()) {
    encoder.swapValue(&sexo);
    if (sexo == 0) {
      display.writeLine(1, "Sexo: varon");
    } else if (sexo == 1) {
      display.writeLine(1, "Sexo: mujer");
    }
  }
  display.writeLine(0, "Sexo seleccionado");
  if (sexo == 0) {
    display.writeLine(1, "Sexo: varon");
  } else if (sexo == 1) {
    display.writeLine(1, "Sexo: mujer");
  }
  Serial.println("Sexo (0:V, 1:M): " + String(sexo));
  delay(1000);
  display.clear();


  // ESTIMACIÓN: VOLUMEN TIDAL
  // =========================================================================
  display.writeLine(0, "Volumen tidal");
  // TODO: calcular volumen tidal estimado en función de la estatura
  calcularVolumenTidal(&volumenTidal, estatura, sexo);
  display.writeLine(1, String(volumenTidal) + " ml");
  Serial.println("Volumen tidal estimado (ml): " + String(volumenTidal));
  delay(2000);
  display.clear();


  // INTERACCIÓN: VOLUMEN TIDAL
  // =========================================================================
  display.writeLine(0, "Modifica volumen");
  while(!encoder.readButton()) {
    encoder.updateValue(&volumenTidal, 10);
    volumenTidal = constrain(volumenTidal, DEFAULT_MIN_VOLUMEN_TIDAL, DEFAULT_MAX_VOLUMEN_TIDAL);
    display.writeLine(1, String(volumenTidal) + " ml");
  }
  display.writeLine(0, "Valor guardado");
  display.writeLine(1, String(volumenTidal) + " ml");
  Serial.println("Volumen tidal configurado (ml): " + String(volumenTidal));
  delay(1000);
  display.clear();


  // INTERACCIÓN: TRIGGER SI/NO
  // =========================================================================
  display.writeLine(0, "Trigger?");
  while(!encoder.readButton()) {
    encoder.swapValue(&tieneTrigger);
    if (tieneTrigger) {
      display.writeLine(1, "Si");
    } else {
      display.writeLine(1, "No");
    }
  }
  display.writeLine(0, "Valor guardado");
  if (tieneTrigger) {
    display.writeLine(1, "Trigger: Si");
  } else {
    display.writeLine(1, "Trigger: No");
  }
  Serial.println("Trigger (0:No, 1:Si): " + String(tieneTrigger));
  delay(1000);
  display.clear();


  // INTERACCIÓN: VALOR DEL TRIGGER
  // =========================================================================
  if (tieneTrigger) {
    display.writeLine(0, "Modifica trigger");
    while(!encoder.readButton()) {
      encoder.updateValue(&flujoTrigger, 0.1);
      display.writeLine(1, "Flujo: " + String(flujoTrigger) + " LPM");
    }
    display.writeLine(0, "Valor guardado");
    display.writeLine(1, "Flujo: " + String(flujoTrigger) + " LPM");
    Serial.println("Flujo trigger (LPM): " + String(flujoTrigger));
    delay(1000);
    display.clear();
  }


  // INTERACCIÓN: FRECUENCIA RESPIRATORIA
  // =========================================================================
  display.writeLine(0, "Frecuencia resp.");
  while(!encoder.readButton()) {
    encoder.updateValue(&rpm);
    rpm = constrain(rpm, DEFAULT_MIN_RPM, DEFAULT_MAX_RPM);
    display.writeLine(1, String(rpm) + " rpm");
  }
  display.writeLine(0, "Valor guardado");
  display.writeLine(1, String(rpm) + " rpm");
  Serial.println("Frecuencia respiratoria (rpm): " + String(rpm));
  delay(1000);
  display.clear();


  // CÁLCULO: CONSTANTES DE TIEMPO INSPIRACION/ESPIRACION
  // =========================================================================
  display.writeLine(0, "Tins | Tesp (seg)");
  calcularCicloInspiratorio(&speedIns, &speedEsp, &tIns, &tEsp,
                            &tCiclo, pasosPorRevolucion, microStepper,
                            porcentajeInspiratorio, rpm);
  display.writeLine(1, String(tIns) + " s" + String(tEsp) + " s");
  Serial.println("Tiempo del ciclo (seg):" + String(tCiclo));
  Serial.println("Tiempo inspiratorio (seg):" + String(tIns));
  Serial.println("Tiempo espiratorio (seg):" + String(tEsp));
  Serial.println("Velocidad 1 calculada:" + String(speedIns));
  Serial.println("Velocidad 2 calculada:" + String(speedEsp));
  delay(2000);
  display.clear();

  // INFORMACIÓN: PARÁMETROS
  // =========================================================================
  display.writeLine(0, "Vol: " + String(volumenTidal) + " ml | " + "Frec: " + String(rpm) + " rpm");
  if (tieneTrigger) {
    display.writeLine(1, "Trigger: " + String(flujoTrigger) + " LPM");
  } else {
    display.writeLine(1, "No trigger");
  }
  delay(2000);


  // INTERACCIÓN: ARRANQUE
  // =========================================================================
  display.writeLine(0, "Pulsa para iniciar");
  display.writeLine(1, "Esperando...");
  while(!encoder.readButton());
  display.clear();
  display.writeLine(1, "Iniciando...");

  // Habilita el motor
  digitalWrite(ENpin, HIGH);

  // configura la ventilación
  if (tieneTrigger) {
    ventilation = MechVentilation(volumenTidal, tIns, tEsp, speedIns, speedEsp, flujoTrigger);
  } else {
    ventilation = MechVentilation(volumenTidal, tIns, tEsp, speedIns, speedEsp);
  }
  ventilation.start();
  delay(500);
  display.clear();
}

// =========================================================================
// LOOP
// =========================================================================

void loop() {
  display.writeLine(0, "Operando...");
  // TODO: display.writeLine(1, "TODO Prompt ventilation status");
  ventilation.update();


  // TODO: si hay nueva configuración: cambiar parámetros escuchando entrada desde el encoder


  // TODO: chequear trigger
  // si hay trigger, esperar al flujo umbral para actuar, si no, actuar en cada bucle


  // Si está en inspiración: controlar con PID el volumen tidal (el que se insufla)

  // Si está en espiración: soltar balón (mover leva hacia arriba sin controlar) y esperar


  // ======================================================================
  // CÓDIGO OBSOLETO DE AQUÍ PARA ABAJO
  // ======================================================================

  // Parte menu
  // display.update(encoder.read());

  // Parte stepper
  stepper.run();

  //recalcular valores por si han cambiado en el menu
  // TODO: sustituir por nueva funcion: calcularConstantes();

  // Primera mitad del ciclo
  if (!stepper.isRunning() && modo && !errorFC) {
    Serial.println("Modo 1");
    stepper.setMaxSpeed(speedIns * microStepper);

    stepper.move(pasosPorRevolucion * microStepper / 2);
    modo = !modo;
  }

  // Segunda mitad del ciclo
  if (!stepper.isRunning() && !modo && !errorFC) {
    Serial.println("Modo 2");

    //se ha llegado al final de carrera en el momento que toca pensar que esta defino como pullup
    if (digitalRead(ENDSTOPpin)) {
      Serial.println("Final de carrera OK");
      stepper.setMaxSpeed(speedEsp * microStepper);
      stepper.move(pasosPorRevolucion * microStepper / 2);
      modo = !modo;
    }
    // si acabada la segunda parte del movimiento no se ha llegado al SENSOR HALL entonces da un paso y vuelve a hacer la comprovocacion
    else {
      Serial.println("Final de carrera NO DETECTADO: Buscando FC");
      errorFC = true;
      digitalWrite(BUZZpin, true); //activa el zumbador
      stepper.move(1 * microStepper);
    }
  }

  //si estamos en error y ha hecho los pasos extra en busca del Final de Carrera
  if (!stepper.isRunning() && errorFC) {
    // no se ha llegado al final suena el BUZZ y ordena dar 3 pasos en busca del FC
    if (!digitalRead(ENDSTOPpin)) {
      Serial.println("--Buscando FC");
      errorFC = true;
      stepper.move(1);
    }
    // cuando lo ha localizado ordena seguir con velocidad 2
    else {
      Serial.println("Detectado FC: restableciendo el origen");
      errorFC = false;
      digitalWrite(BUZZpin, false); //apaga el zumbador
      stepper.setMaxSpeed(speedEsp * microStepper);
      stepper.move(pasosPorRevolucion * microStepper / 2);
      modo = !modo; //cambiamos de velocidad
    }
  }
  // si hay un error pero ha hecho los 100 pasos extra en busca del Final de Carrera
  else if (!stepper.isRunning() && errorFC) {
    // no se ha llegado al final suena el BUZZ y ordena dar 3 pasos en busca del FC
    if (digitalRead(ENDSTOPpin)) {
      errorFC = true;
      stepper.move(1);
      digitalWrite(BUZZpin, true);
      Serial.println("ZUMBA");
    }
    // cuando lo ha localizado ordena seguir con velocidad 2
    else {
      errorFC = false;
      digitalWrite(BUZZpin, false);
      stepper.setMaxSpeed(speedEsp);
      stepper.move(pasosPorRevolucion / 2);
    }
  }
}

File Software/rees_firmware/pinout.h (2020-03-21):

#ifndef PINOUT_H
#define PINOUT_H

#include "Arduino.h"

//Display

#define LCD_ROWS 2
#define LCD_COLS 16

#ifdef I2C  //i2c

//D irección de LCD I2C
#define I2C_DIR 0x3F

#else

// pines Display parallel  // parallel
#define LCD_RS A0
#define LCD_E  A1
#define LCD_D4 A2
#define LCD_D5 A3
#define LCD_D6 A4
#define LCD_D7 A5

#endif // I2C

// Rotary encoder
#define CLKpin 2
#define DTpin 3
#define SWpin 9

// Stepper driver
#define PULpin 6
#define DIRpin 7
#define ENpin 8

// Buzzer
#define BUZZpin 11

// Sensor hall
#define ENDSTOPpin 5

#endif // ENCODER_H

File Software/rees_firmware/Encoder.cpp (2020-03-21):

#include "Encoder.h"
#include "Arduino.h"

const int8_t KNOBDIR[] = {
     0, -1,  1,  0,
     1,  0,  0, -1,
    -1,  0,  0,  1,
     0,  1, -1,  0
};

Encoder::Encoder(int pin1, int pin2, int pulsador) {
  _pin1 = pin1;
  _pin2 = pin2;
  _pulsador = pulsador;

  // Setup the input pins and turn on pullup resistor
  pinMode(pin1, INPUT_PULLUP);
  pinMode(pin2, INPUT_PULLUP);
  pinMode(pulsador, INPUT_PULLUP);

  // when not started in motion, the current state of the encoder should be 3
  _oldState = 3;

  // start with position 0;
  _position = 0;
  _positionExt = 0;
  _positionExtPrev = 0;
  _flag = false;
  _tiempo = 0;
}

long Encoder::getPosition() {
  return _positionExt;
}

// unused
int Encoder::getDirection() {

  int ret = 0;

  if (_positionExtPrev > _positionExt) {
    ret = -1;
    _positionExtPrev = _positionExt;
  }
  else if (_positionExtPrev < _positionExt) {
    ret = 1;
    _positionExtPrev = _positionExt;
  }
  else {
    ret = 0;
    _positionExtPrev = _positionExt;
  }

  return ret;
}

// unused
void Encoder::setPosition(long newPosition) {
  _position = ((newPosition << 2) | (_position & 0x03L));
  _positionExt = newPosition;
  _positionExtPrev = newPosition;
}

void Encoder::tick(void) {
  int sig1 = digitalRead(_pin1);
  int sig2 = digitalRead(_pin2);
  int8_t thisState = sig1 | (sig2 << 1);

  if (_oldState != thisState)   {
    _position += KNOBDIR[thisState | (_oldState << 2)];

    if (thisState == LATCHSTATE)
      _positionExt = _position >> 2;

    _oldState = thisState;
  }
}

/**
 * @brief Modifica un valor dicotómico entre 0 y 1.
 *
 * Cuando se gira el encoder, el valor se pasa de 0 a 1 y
 * de 1 a 0 cada vez que se mueve el dial.
 *
 * @param valor valor a actualizar
 */
void Encoder::swapValue(int* valor) {
  // Giramos horario o antihorario
  if (read() == 2 || read() == 8) {
    if (*valor == 0) {
      *valor = 1;
    } else if (*valor == 1) {
      *valor = 0;
    }
  }
}

void Encoder::swapValue(bool* valor) {
  // Giramos horario o antihorario
  if (read() == 2 || read() == 8) {
    *valor = !(*valor);
  }
}

/**
 * @brief Altera un valor entero un incremento delta.
 *
 * Incrementa (antihorario) o decrementa (horario) un
 * valor dado, un delta determinado.
 *
 * @param valor valor a actualizar
 * @param delta incremento, por defecto: 1
 */
void Encoder::updateValue(int* valor, int delta) {
  // Giramos horario (Subimos en el menu)
  if (read() == 2) {
    *valor = *valor - delta;
  // Giramos antihorario (Subimos en el menu)
  } else if (read() == 8) {
    *valor = *valor + delta;
  }
}

void Encoder::updateValue(float* valor, float delta) {
  // Giramos horario (Subimos en el menu)
  if (read() == 2) {
    *valor = *valor - delta;
  // Giramos antihorario (Subimos en el menu)
  } else if (read() == 8) {
    *valor = *valor + delta;
  }
}

/**
 * @brief Lee la señal emitida al pulsar el encoder
 *
 * @return true cuando se pulsa
 * @return false si no se ha pulsado
 */
bool Encoder::readButton() {
  if (digitalRead(_pulsador) != 1) {
    if (!_flag) {
      _tiempo = millis();
      _flag = true;
    }
    while (digitalRead(_pulsador) == 0) {
      if (millis() - _tiempo > 300) {
        _flag = false;
        return true;
      }
    }
  }
  return false;
}

/**
 * @brief Lee el giro del knob del encoder.
 *
 * @return int giro antihorario: 8, giro horario: 2
 */
int Encoder::read() {
  static int _pos = 0;
  tick();
  int _newPos = getPosition();

  // Giramos antihorario (Subimos en el menu)
  if (_pos > _newPos) {
    _pos = _newPos;
    return 8;
  }
  // Giramos horario (Subimos en el menu)
  else if (_pos < _newPos) {
    _pos = _newPos;
    return 2;
  }
  // Pulsamos (Modificamos valor)
  if (readButton()) {
    return 5;
  }
  return 0;
}

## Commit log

2020-03-21 Subiendo contenido de Reespirator
    Subo el Git de Reespirartor
    [022057038.stp, 022057048.stp, 22057028.stp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]
2020-03-21 Informacion tecnica para imprimir
    Adjunto los datos tecnicos y perfiles para la impresion
2020-03-21 Mejoras varias
    -Eliminacion de la pieza Acople
    -Correcion un error de anguno en el diseño
    -Se rediseño la leva completamente desde cero, manteniendo dimenciones originales en tamaño, el canto fue rediseñado con un radio de 5mm para que se almolde al rodamiento del brazo.
    -se intrego un sistema de acople directo, elimiando 4 tornillos, solo requiere uno para presionar el motor.
    [Leva.stl]
2020-03-21 Escuadras
    Para sujertar el respirador al chasis, importante respetar la posicion de impresion
    [Escuadra_B.stl, Escuadra_a.stl]
2020-03-21 Placas a y b compatibles con las escuadras
    agregue un sistema de encastre para las escuadras
    [Placa_a.stl, Placa_b.stl]
2020-03-21 Reorganizacion de carpetas
    Divido los diseños entre pruebas y finales, recomiendo esperar a que las piezas sean aprobadas
    [Ambu_a.stl, Ambu_b.stl, Brazo.stl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]
2020-03-22 Update Presionador.stl
    Rediseño para evitar soporte de impresion
    [Presionador.stl]
2020-03-22 Listo
    La leva ya se encuentra en diseño final
    [Leva final.stl, Leva.stl, Probar acople.stl]
2020-03-22 Agrego el archivo editable del Fusion360
    En este archivo se encuentra el diseño con todas sus revisiones, el chasis esta en progreso
2020-03-22 Moviendo archivos finalizados
    Archivos listos para imprimir
    [Ambu_a.stl, Ambu_b.stl, Escuadra_B.stl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]
2020-03-22 Brazo final
    Se agrego un tope al rodamiento 608
    [Brazo.stl]
2020-03-22 Create guia leva.stl
    [guia leva.stl]
2020-03-23 Update Leva final.stl
    [Leva final.stl]
2020-03-25 Update Presionador.stl
    Arreglo en algunos vertices
    [Presionador.stl]
